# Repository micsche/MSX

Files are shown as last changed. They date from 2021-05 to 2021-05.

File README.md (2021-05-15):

# MSX
Recreate a Z80 system using MSX2 standard. 

The system is subdivided into 5 boards connected by a BUS. 

1. msx1-cpu: This is the CPU board complete with CPU, Clock circuit, Reset Circuit, IO Address decoder and default MSX Wait circuit.
2. msx1-memory : This is the 64k ROM/ 64k RAM circuit and a USB Serial connection via CJMCU-232H. Currently this is an MSX1 standard. 
3. msx1-keyb-ppi : This is the Keyboard connector circuit and the Memory Slot selector circuit
4. msx1-psg: This is the sound circuit (using YM2149). Joystick interface not implemented.
5. msx1-vdp: This is the video circuit (using TMS9958). To be completed: VRAM  of 96k possible.

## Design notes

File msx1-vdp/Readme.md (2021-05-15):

# MSX Video

This is a work in progress.

The VDP9958 is used (although this is not used until the MSX2+ standard)

The chip requires the use of DRAM chips. The use of SRAM would require complex address decode, out of the scope of this board development.
A 128k VRAM is possible with V9958.

The Video chips use the Z80 interrupt signal and also provide a CPU clock signal.

The video signal needs to be modified for use of new displays. LED displays cannot handle the 15kHz HSYNC frequency used by the chip.

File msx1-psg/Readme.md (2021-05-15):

# MSX Sound card 
(untested)

The soundcard uses stock YM2149 (AY-3-8910 clone)
The MSX also uses this chip to interface to the joysticks. This version of the board does not include joystick ports (scope for Future Work).

The sound is fed into the BUS pin J3-8. However, the board has enough space to include a small-speaker. (scope for Future Work)

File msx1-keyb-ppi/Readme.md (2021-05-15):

# MSX PPI - Keyboard Interface (as of writing untested)

This board has two functions:
1. Interface with a matrix keyboard (in progress), including an LED output for the CAPS lock key.
2. Provide SLOT Signalling standard of MSX

## Keyboard

The board has a DB25 connector where a keyboard is to be connected.
    


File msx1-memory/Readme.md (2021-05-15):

# MSX Memory Board

The aim of the board is to use stock ROM and SRAM,  had available. Although the ROM and RAM used are 128k, only 64k are used. An MSX memory mapper is a future project.
For MSX to use the memory the PPI board is a required board since it decodes the Memory Slot SLTSL signal. In this case SLOT0 is used for ROM and SLOT3 is used for RAM. However, for the SBC there is included a simple decoder that can be switched off.

The MSX1 standard: ROM is using the first 32k address 0000-7FFF (normally at SLOT0), and 8k-32k RAM the subsequent 8000-FFFF (Normally at SLOT3).
- https://www.msx.org/wiki/The_Memory
- https://konamiman.github.io/MSX2-Technical-Handbook/md/Chapter1.html#1-from-msx1-to-msx2



## Using the board for SBC operation
This board is adapted to be used as an SBC. A modification on the ROM should remove the A15 address decoding to use just 32k.
This is done using a 74LS139 that decodes the A15 and MREQ to produce the SLTSL0 and SLTSL3 selector signals. 
When used in MSX mode the 74LS139 can be disabled by disconnecting jumper SimpleMem (which powers the Logic Circuit).

## Serial Connection
The board also uses the IO Serial signal to connect a USB Serial connection to the Z80 databus. The circuit interfaces with a breakout board CJMCU-232H, which is TTL compliant.

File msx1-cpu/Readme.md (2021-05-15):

The aim of the board is to use stock hardware without the use of FPGAs, CPLDs, logic arrays, etc...
The chip count as a result increases considerably.

# MSX CPU board

This is a default CPU board complete with 
1. 3.58MHz clock circuit using a NAND invertor circuit. The board can choose which clock to using Jumpers CLK_EXT. Using an external clock circuit allows you to clock down the circuit for troubleshooting (logic analyser) or else use the VDPs own clock circuitry. 
The clock circuitry is included so that with the CPU board and Memory board, is effectively a standalone Z80 computer (SBC but not quite).

2. A reset circuit is included, with a Jumper (RESET_SWITCH) to connect an external reset button. Two signals are created RESET and ~RESET.
3. IO Signal circuitry. M1 and IORQ signal IO is being accessed. IO allocation reference: http://map.grauw.nl/resources/msx_io_ports.php
4. A wait circuit is used for slower Memory. Speedup modiciations include disabling this circuitry altogether. https://www.msx.org/forum/msx-talk/hardware/speeding-z80
5. 50-channel bus: Bus used to connect all the other boards together. This is not the cartridge bus as used by the MSX standard. The Bus includes
    i. Z80 Address Bus
    ii. Z80 Data Bus
    iii. Control Signals (CLK,INT, RD, WR, RESET,MREQ, IORQ)
    iv. IO Signals (rtc,ppi,psg,vdp,prn,exp,ser)
    


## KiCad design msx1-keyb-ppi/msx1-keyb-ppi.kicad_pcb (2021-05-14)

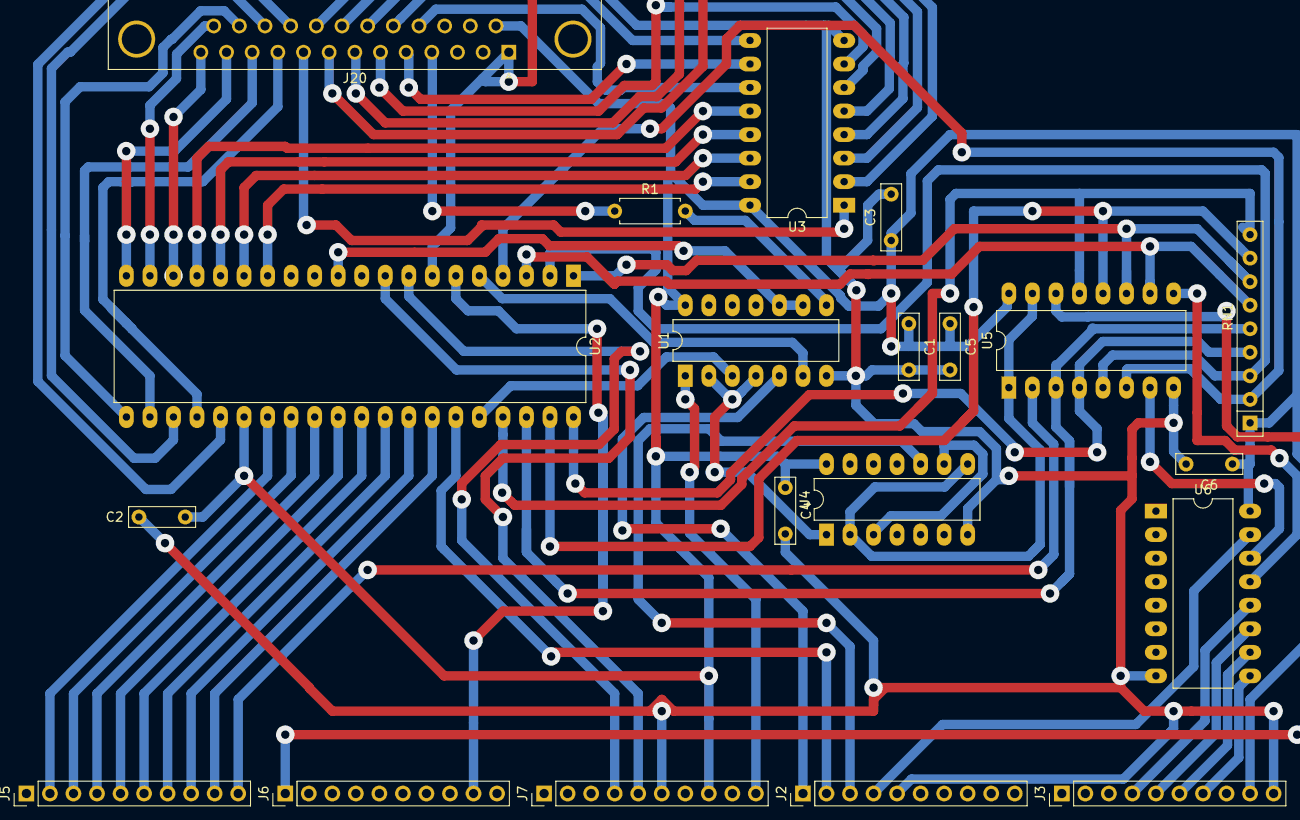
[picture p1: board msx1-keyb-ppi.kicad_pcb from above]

Board: 2 copper layers, 20 parts (0 on the bottom side), 64 nets.

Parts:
C1, C2, C3, C4, C5, C6: 100n; C_Rect_L7.0mm_W2.0mm_P5.00mm
J2, J3, J5, J6, J7: Conn_01x10; PinHeader_1x10_P2.54mm_Vertical
J20: DB25_Male_MountingHoles; DSUB-25_Male_Horizontal_P2.77x2.84mm_EdgePinOffset7.70mm_Ho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
R1: R; R_Axial_DIN0207_L6.3mm_D2.5mm_P7.62mm_Horizontal
RN1: 3.3k; R_Array_SIP9
U1: 74LS32; DIP-14_W7.62mm_LongPads
U2: PPI; DIP-40_W15.24mm_LongPads
U3: 74LS45; DIP-16_W10.16mm_LongPads
U4: 74LS00; DIP-14_W7.62mm_LongPads
U5: 74LS153; DIP-16_W10.16mm_LongPads
U6: 74LS139; DIP-16_W10.16mm_LongPads

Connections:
+5V: C1.1, C2.1, C3.1, C4.1, C5.1, C6.1, J3.9, J7.8, J20.14, RN1.1, U1.14, U2.26, U3.16, U4.14, U5.16, U6.16
A0: J7.5, U2.9
A1: J7.4, U2.8
A6: J6.9, U2.6
A14: J6.1, U5.14
A15: J5.10, U5.2
CAPS: J20.4, R1.1
D0: J5.9, U2.34
D1: J5.8, U2.33
D2: J5.7, U2.32
D3: J5.6, U2.31
D4: J5.5, U2.30
D5: J5.4, U2.29
D6: J5.3, U2.28
D7: J5.2, U2.27
GND: C1.2, C2.2, C3.2, C4.2, C5.2, C6.2, J2.5, J3.10, J7.6, J20.1, U1.7, U2.7, U3.8, U4.7, U5.8, U6.8
unnamed: R1.2, U1.8
unnamed: RN1.2, U2.4, U5.6
unnamed: RN1.3, U2.2, U5.5
unnamed: RN1.4, U2.40, U5.4
unnamed: RN1.5, U2.38, U5.3
unnamed: RN1.6, U2.3, U5.10
unnamed: RN1.7, U2.1, U5.11
unnamed: RN1.8, U2.39, U5.12
unnamed: RN1.9, U2.37, U5.13
unnamed: U1.3, U2.36
unnamed: U1.6, U2.5
unnamed: U1.9, U1.10, U2.11
unnamed: U2.14, U3.15
unnamed: U2.15, U3.14
unnamed: U2.16, U3.13
unnamed: U2.17, U3.12
unnamed: U4.2, U4.8, U5.1, U5.15
unnamed: U4.3, U4.9
unnamed: U5.7, U6.14
unnamed: U5.9, U6.13
RESET: J2.2, U2.35
S0: J20.13, U2.18
S1: J20.25, U2.19
S2: J20.12, U2.20
S3: J20.24, U2.21
S4: J20.11, U2.22
S5: J20.23, U2.23
S6: J20.10, U2.24
S7: J20.22, U2.25
Y0: J20.9, U3.1
Y1: J20.21, U3.2
Y2: J20.8, U3.3
Y3: J20.20, U3.4
Y4: J20.7, U3.5
Y5: J20.19, U3.6
Y6: J20.6, U3.7
Y7: J20.18, U3.9
Y8: J20.5, U3.10
Y9: J20.17, U3.11
~MREQ: J2.4, U6.15
~PPI: U1.2, U1.4, U4.1
~RD: J2.1, U1.5
~RESET: J2.3, U4.10
~SLTSL0: J3.4, U6.12
~SLTSL1: J3.5, U6.11
~SLTSL2: J3.6, U6.10
~SLTSL3: J3.7, U6.9
~WR: J7.10, U1.1

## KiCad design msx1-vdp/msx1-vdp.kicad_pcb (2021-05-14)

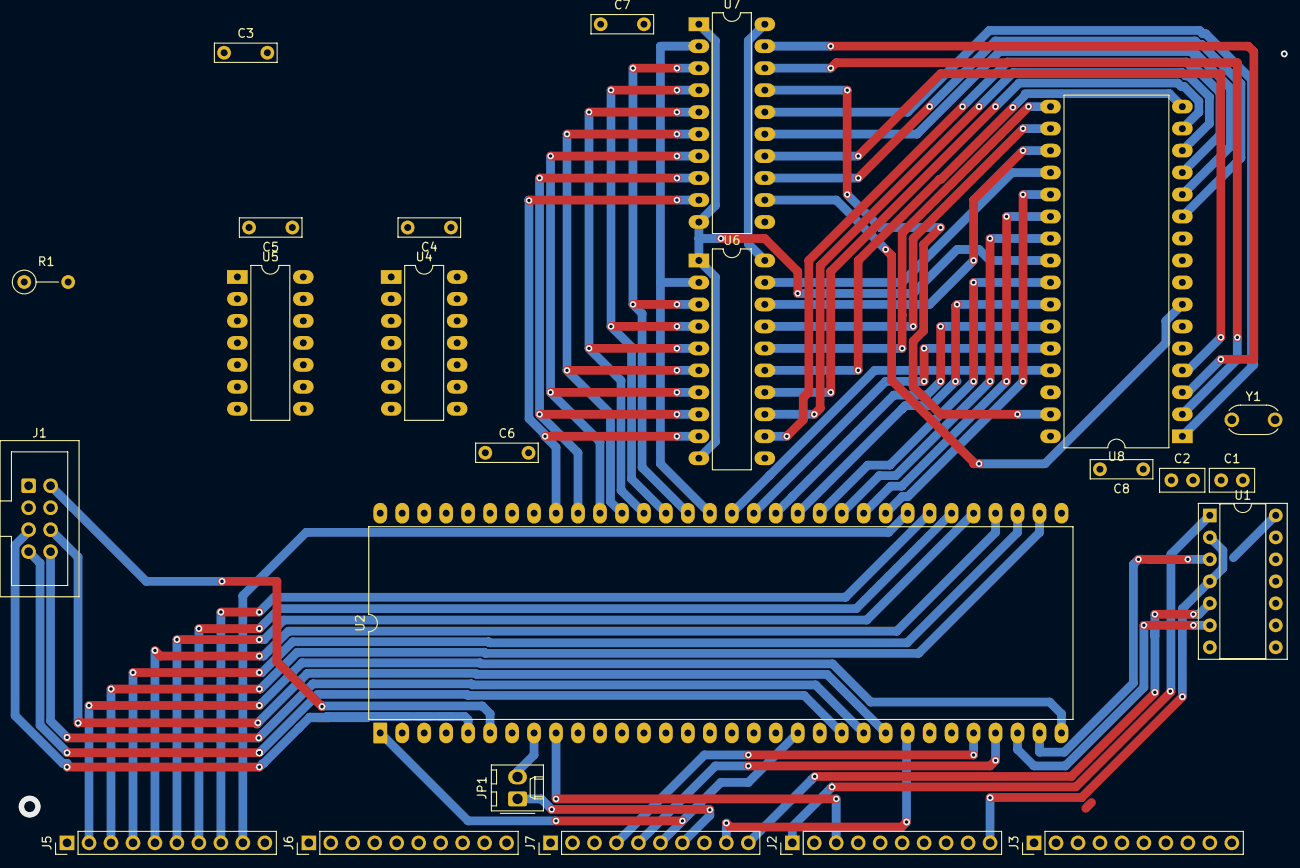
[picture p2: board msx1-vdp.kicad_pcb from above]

Board: 2 copper layers, 24 parts (0 on the bottom side), 70 nets.

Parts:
C1: 15pf; C_Disc_D5.0mm_W2.5mm_P2.50mm
C2: 7pF; C_Disc_D5.0mm_W2.5mm_P2.50mm
C3, C4, C5, C6, C7, C8: C; C_Rect_L7.0mm_W2.0mm_P5.00mm
J1: Conn_02x03_Counter_Clockwise; IDC-Header_2x04_P2.54mm_Vertical
J2, J3, J5, J6, J7: Conn_01x10; PinHeader_1x10_P2.54mm_Vertical
JP1: Jumper_NO_Small; Molex_KK-254_AE-6410-02A_1x02_P2.54mm_Vertical
R1: 330; R_Axial_DIN0207_L6.3mm_D2.5mm_P5.08mm_Vertical
U1: 74LS32; DIP-14_W7.62mm_Socket
U2: TMS9958-MSX; DIP-64_W25.4mm_LongPads
U4: 74LS00; DIP-14_W7.62mm_LongPads
U5: 74LS74; DIP-14_W7.62mm_LongPads
U6, U7: 74LS574; DIP-20_W7.62mm_LongPads
U8: 551001; DIP-32_W15.24mm_LongPads
Y1: 21.47727MHz; Resonator-2Pin_W6.0mm_H3.0mm

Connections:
+5V: C3.1, C4.1, C5.1, C6.1, C7.1, C8.1, J1.1, J3.9, J7.8, U1.14, U2.21, U2.58, U4.14, U5.4, U5.14, U6.20, U7.20, U8.8
A0: J7.5, U2.29
A1: J7.4, U2.28
ADD_DATA_0: U2.49, U6.2, U7.2
ADD_DATA_1: U2.50, U6.3, U7.3
ADD_DATA_2: U2.51, U6.4, U7.4
ADD_DATA_3: U2.52, U6.5, U7.5
ADD_DATA_4: U2.53, U6.6, U7.6
ADD_DATA_5: U2.54, U6.7, U7.7
ADD_DATA_6: U2.55, U6.8, U7.8
ADD_DATA_7: U2.56, U6.9, U7.9
B: J1.6, U2.24
CAS: U4.3, U4.12, U4.13, U5.3, U7.11
CLK: J7.7, JP1.1
CSYNC: J1.2, U2.6
D0: J5.9, U2.40
D1: J5.8, U2.39
D2: J5.7, U2.38
D3: J5.6, U2.37
D4: J5.5, U2.36
D5: J5.4, U2.35
D6: J5.3, U2.34
D7: J5.2, U2.32
DATA0: U2.41, U8.21
DATA1: U2.42, U8.22
DATA2: U2.43, U8.23
DATA3: U2.44, U8.25
DATA4: U2.45, U8.26
DATA5: U2.46, U8.27
DATA6: U2.47, U8.28
DATA7: U2.48, U8.29
G: J1.7, U2.22
GND: C1.1, C2.1, C3.2, C4.2, C5.2, C6.2, C7.2, C8.2, J1.4, J2.5, J3.10, J7.6, U1.7, U2.1, U2.20, U4.7, U5.1, U5.7, U6.1, U6.10, U7.1, U7.10, U8.24
unnamed: C1.2, R1.1, Y1.1
unnamed: C2.2, U2.63, Y1.2
unnamed: JP1.2, U2.8
unnamed: R1.2, U2.64
unnamed: U1.3, U2.31
unnamed: U1.6, U2.30
unnamed: U2.60, U4.2, U5.2
unnamed: U2.61, U4.1
unnamed: U4.6, U6.11
unnamed: U4.8, U8.32
unnamed: U4.11, U8.6, U8.30
unnamed: U5.5, U8.10
unnamed: U6.12, U8.13
unnamed: U6.13, U8.14
unnamed: U6.14, U8.15
unnamed: U6.15, U8.16
unnamed: U6.16, U8.17
unnamed: U6.17, U8.18
unnamed: U6.18, U8.19
unnamed: U6.19, U8.20
unnamed: U7.12, U8.7
unnamed: U7.13, U8.11
unnamed: U7.14, U8.4
unnamed: U7.15, U8.12
unnamed: U7.16, U8.1
unnamed: U7.17, U8.31
unnamed: U7.18, U8.2
unnamed: U7.19, U8.3
R: J1.8, U2.23
R_~W: U2.57, U4.9, U4.10, U8.5
vdp_en: J2.10, U1.2, U1.4
~HSYNC: J1.5, U2.5
~INT: J7.9, U2.25
~RAS: U2.62, U4.4, U4.5
~RD: J2.1, U1.1
~RESET: J2.3, U2.9
~WR: J7.10, U1.5

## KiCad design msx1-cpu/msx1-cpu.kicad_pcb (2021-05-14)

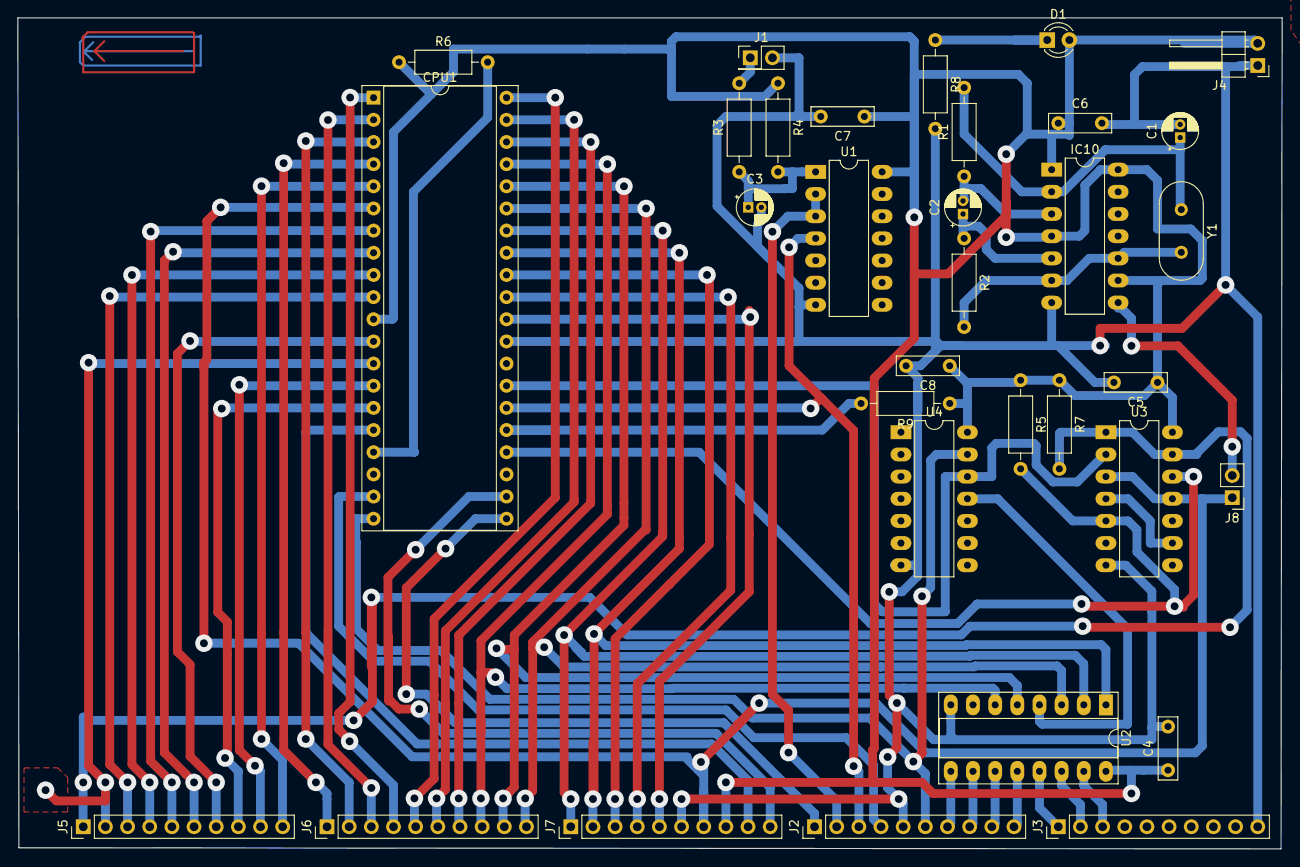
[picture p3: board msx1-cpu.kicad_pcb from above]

Board: 2 copper layers, 144.9 x 95.2 mm, 33 parts (0 on the bottom side), 56 nets.

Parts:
C1: 120p; CP_Radial_D4.0mm_P1.50mm
C2: 100n; CP_Radial_D4.0mm_P1.50mm
C3: 1nF; CP_Radial_D4.0mm_P1.50mm
C4, C5, C7, C8: 100n; C_Rect_L7.0mm_W2.0mm_P5.00mm
C6: 220n; C_Rect_L7.0mm_W2.0mm_P5.00mm
CPU1: Z80CPU; DIP-40_W15.24mm_Socket
D1: LED; LED_D3.0mm_FlatTop
IC10: 74LS00; DIP-14_W7.62mm_LongPads
J1: RESET SWITCH; PinHeader_2x01_P2.54mm_Vertical
J2, J3, J5, J6, J7: Conn_01x10; PinHeader_1x10_P2.54mm_Vertical
J4: Conn_02x01; PinHeader_1x02_P2.54mm_Horizontal
J8: CLK_EXT; PinHeader_1x02_P2.54mm_Vertical
R1, R2: 330; R_Axial_DIN0207_L6.3mm_D2.5mm_P10.16mm_Horizontal
R3: 100R; R_Axial_DIN0207_L6.3mm_D2.5mm_P10.16mm_Horizontal
R4: 47k; R_Axial_DIN0207_L6.3mm_D2.5mm_P10.16mm_Horizontal
R5, R6, R7, R9: 10k; R_Axial_DIN0207_L6.3mm_D2.5mm_P10.16mm_Horizontal
R8: 220; R_Axial_DIN0207_L6.3mm_D2.5mm_P10.16mm_Horizontal
U1: 74HC14; DIP-14_W7.62mm_LongPads
U2: 74LS138; DIP-16_W7.62mm_Socket_LongPads
U3: 74LS74; DIP-14_W7.62mm_LongPads
U4: 74LS32; DIP-14_W7.62mm_LongPads
Y1: 3.58MHz; Crystal_HC18-U_Vertical

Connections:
+5V: C4.1, C5.1, C6.1, C7.1, C8.1, CPU1.11, D1.2, IC10.1, IC10.4, IC10.9, IC10.14, J4.2, J7.8, R4.1, R5.1, R6.1, R7.1, R9.1, U1.14, U2.16, U3.14, U4.14
A0: CPU1.30, J7.5
A1: CPU1.31, J7.4
A2: CPU1.32, J7.3
A3: CPU1.33, J7.2, U2.1
A4: CPU1.34, J7.1, U2.2
A5: CPU1.35, J6.10, U2.3
A6: CPU1.36, J6.9, U2.5
A7: CPU1.37, J6.8, U2.6
A8: CPU1.38, J6.7
A9: CPU1.39, J6.6
A10: CPU1.40, J6.5
A11: CPU1.1, J6.4
A12: CPU1.2, J6.3
A13: CPU1.3, J6.2
A14: CPU1.4, J6.1
A15: CPU1.5, J5.10
CLK: CPU1.6, J7.7, J8.1, U3.3, U3.11
CLK2: IC10.8, J8.2
D0: CPU1.14, J5.9
D1: CPU1.15, J5.8
D2: CPU1.12, J5.7
D3: CPU1.8, J5.6
D4: CPU1.7, J5.5
D5: CPU1.9, J5.4
D6: CPU1.10, J5.3
D7: CPU1.13, J5.2
GND: C1.2, C3.2, C4.2, C5.2, C6.2, C7.2, C8.2, CPU1.29, IC10.7, J1.2, J2.5, J3.10, J4.1, J7.6, R8.2, U1.7, U2.8, U3.7, U4.7
unnamed: C1.1, IC10.2, R1.2, Y1.1
unnamed: C2.1, IC10.5, R2.1
unnamed: C2.2, IC10.3, R1.1
unnamed: C3.1, R3.1, R4.2, U1.1
unnamed: CPU1.17, R6.2
unnamed: CPU1.25, R9.2
unnamed: D1.1, R8.1
unnamed: IC10.6, IC10.10, R2.2, Y1.2
unnamed: J1.1, R3.2
unnamed: U2.4, U4.11
unnamed: U3.4, U3.9
RESET: J2.2, U1.2, U1.3
exp1_en: J3.2, U2.14
ppi_en: J2.8, U2.10
prn_en: J3.1, U2.13
psg_en: J2.9, U2.11
rtc_en: J2.7, U2.9
ser_en: J3.3, U2.15
vdp_en: J2.10, U2.12
~INT: CPU1.16, J7.9
~IORQ: CPU1.20, J2.6, U4.13
~IO_WAIT: J5.1, R7.2, U3.1, U3.13
~M1: CPU1.27, U3.2, U4.12
~MREQ: CPU1.19, J2.4
~RD: CPU1.21, J2.1
~RESET: CPU1.26, J2.3, U1.4
~WAIT: CPU1.24, R5.2, U3.5, U3.12
~WR: CPU1.22, J7.10

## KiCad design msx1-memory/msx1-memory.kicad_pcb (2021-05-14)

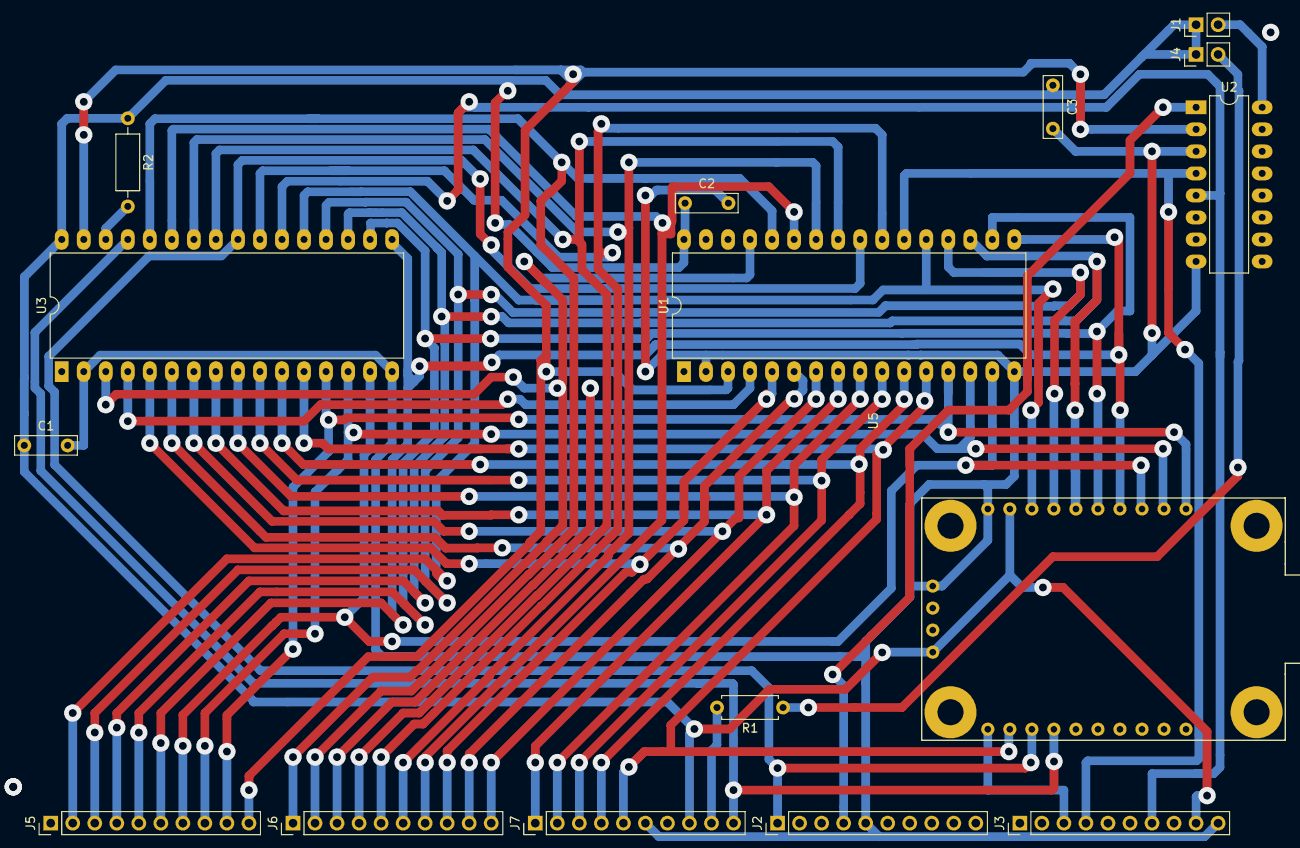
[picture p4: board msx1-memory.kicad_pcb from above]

Board: 2 copper layers, 16 parts (0 on the bottom side), 36 nets.

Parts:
C1, C2, C3: 100n; C_Rect_L7.0mm_W2.0mm_P5.00mm
J1: SimpleMem; PinHeader_1x02_P2.54mm_Vertical
J2, J3, J5, J6, J7: Conn_01x10; PinHeader_1x10_P2.54mm_Vertical
J4: SimpleMem-INT; PinHeader_1x02_P2.54mm_Vertical
R1: 10k; R_Axial_DIN0207_L6.3mm_D2.5mm_P7.62mm_Horizontal
R2: 10k; R_Axial_DIN0207_L6.3mm_D2.5mm_P10.16mm_Horizontal
U1: ROM 29F010; DIP-32_W15.24mm_LongPads
U2: 74LS139; DIP-16_W7.62mm_LongPads
U3: SRAM TC551001; DIP-32_W15.24mm_LongPads
U5: CJMCU-232H; CJMCU-232H-Breakout

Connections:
+5V: C1.1, C2.1, C3.1, J1.1, J3.9, J4.1, J7.8, R2.1, U1.32, U3.32, U5.9, U5.14
A0: J7.5, U1.12, U3.12, U5.16
A1: J7.4, U1.11, U3.11
A2: J7.3, U1.10, U3.10
A3: J7.2, U1.9, U3.9
A4: J7.1, U1.8, U3.8
A5: J6.10, U1.7, U3.7
A6: J6.9, U1.6, U3.6
A7: J6.8, U1.5, U3.5
A8: J6.7, U1.27, U3.27
A9: J6.6, U1.26, U3.26
A10: J6.5, U1.23, U3.23
A11: J6.4, U1.25, U3.25
A12: J6.3, U1.4, U3.4
A13: J6.2, U1.28, U3.28
A14: J6.1, U1.29, U3.3
A15: J5.10, U1.3, U2.2, U3.31
D0: J5.9, U1.13, U3.13, U5.1
D1: J5.8, U1.14, U3.14, U5.2
D2: J5.7, U1.15, U3.15, U5.3
D3: J5.6, U1.17, U3.17, U5.4
D4: J5.5, U1.18, U3.18, U5.5
D5: J5.4, U1.19, U3.19, U5.6
D6: J5.3, U1.20, U3.20, U5.7
D7: J5.2, U1.21, U3.21, U5.8
GND: C1.2, C2.2, C3.2, J2.5, J3.10, J7.6, U1.2, U1.16, U2.3, U2.8, U3.2, U3.16, U5.10, U5.11
unnamed: J1.2, U2.16
unnamed: J4.2, R1.1
unnamed: R2.2, U3.30
ser_en: J3.3, U5.15
~INT: J7.9, R1.2
~MREQ: J2.4, U2.1
~RD: J2.1, U1.24, U3.24, U5.17
~SLTSL0: J3.4, U1.22, U2.4
~SLTSL3: J3.7, U2.5, U3.22
~WR: J7.10, U3.29, U5.18

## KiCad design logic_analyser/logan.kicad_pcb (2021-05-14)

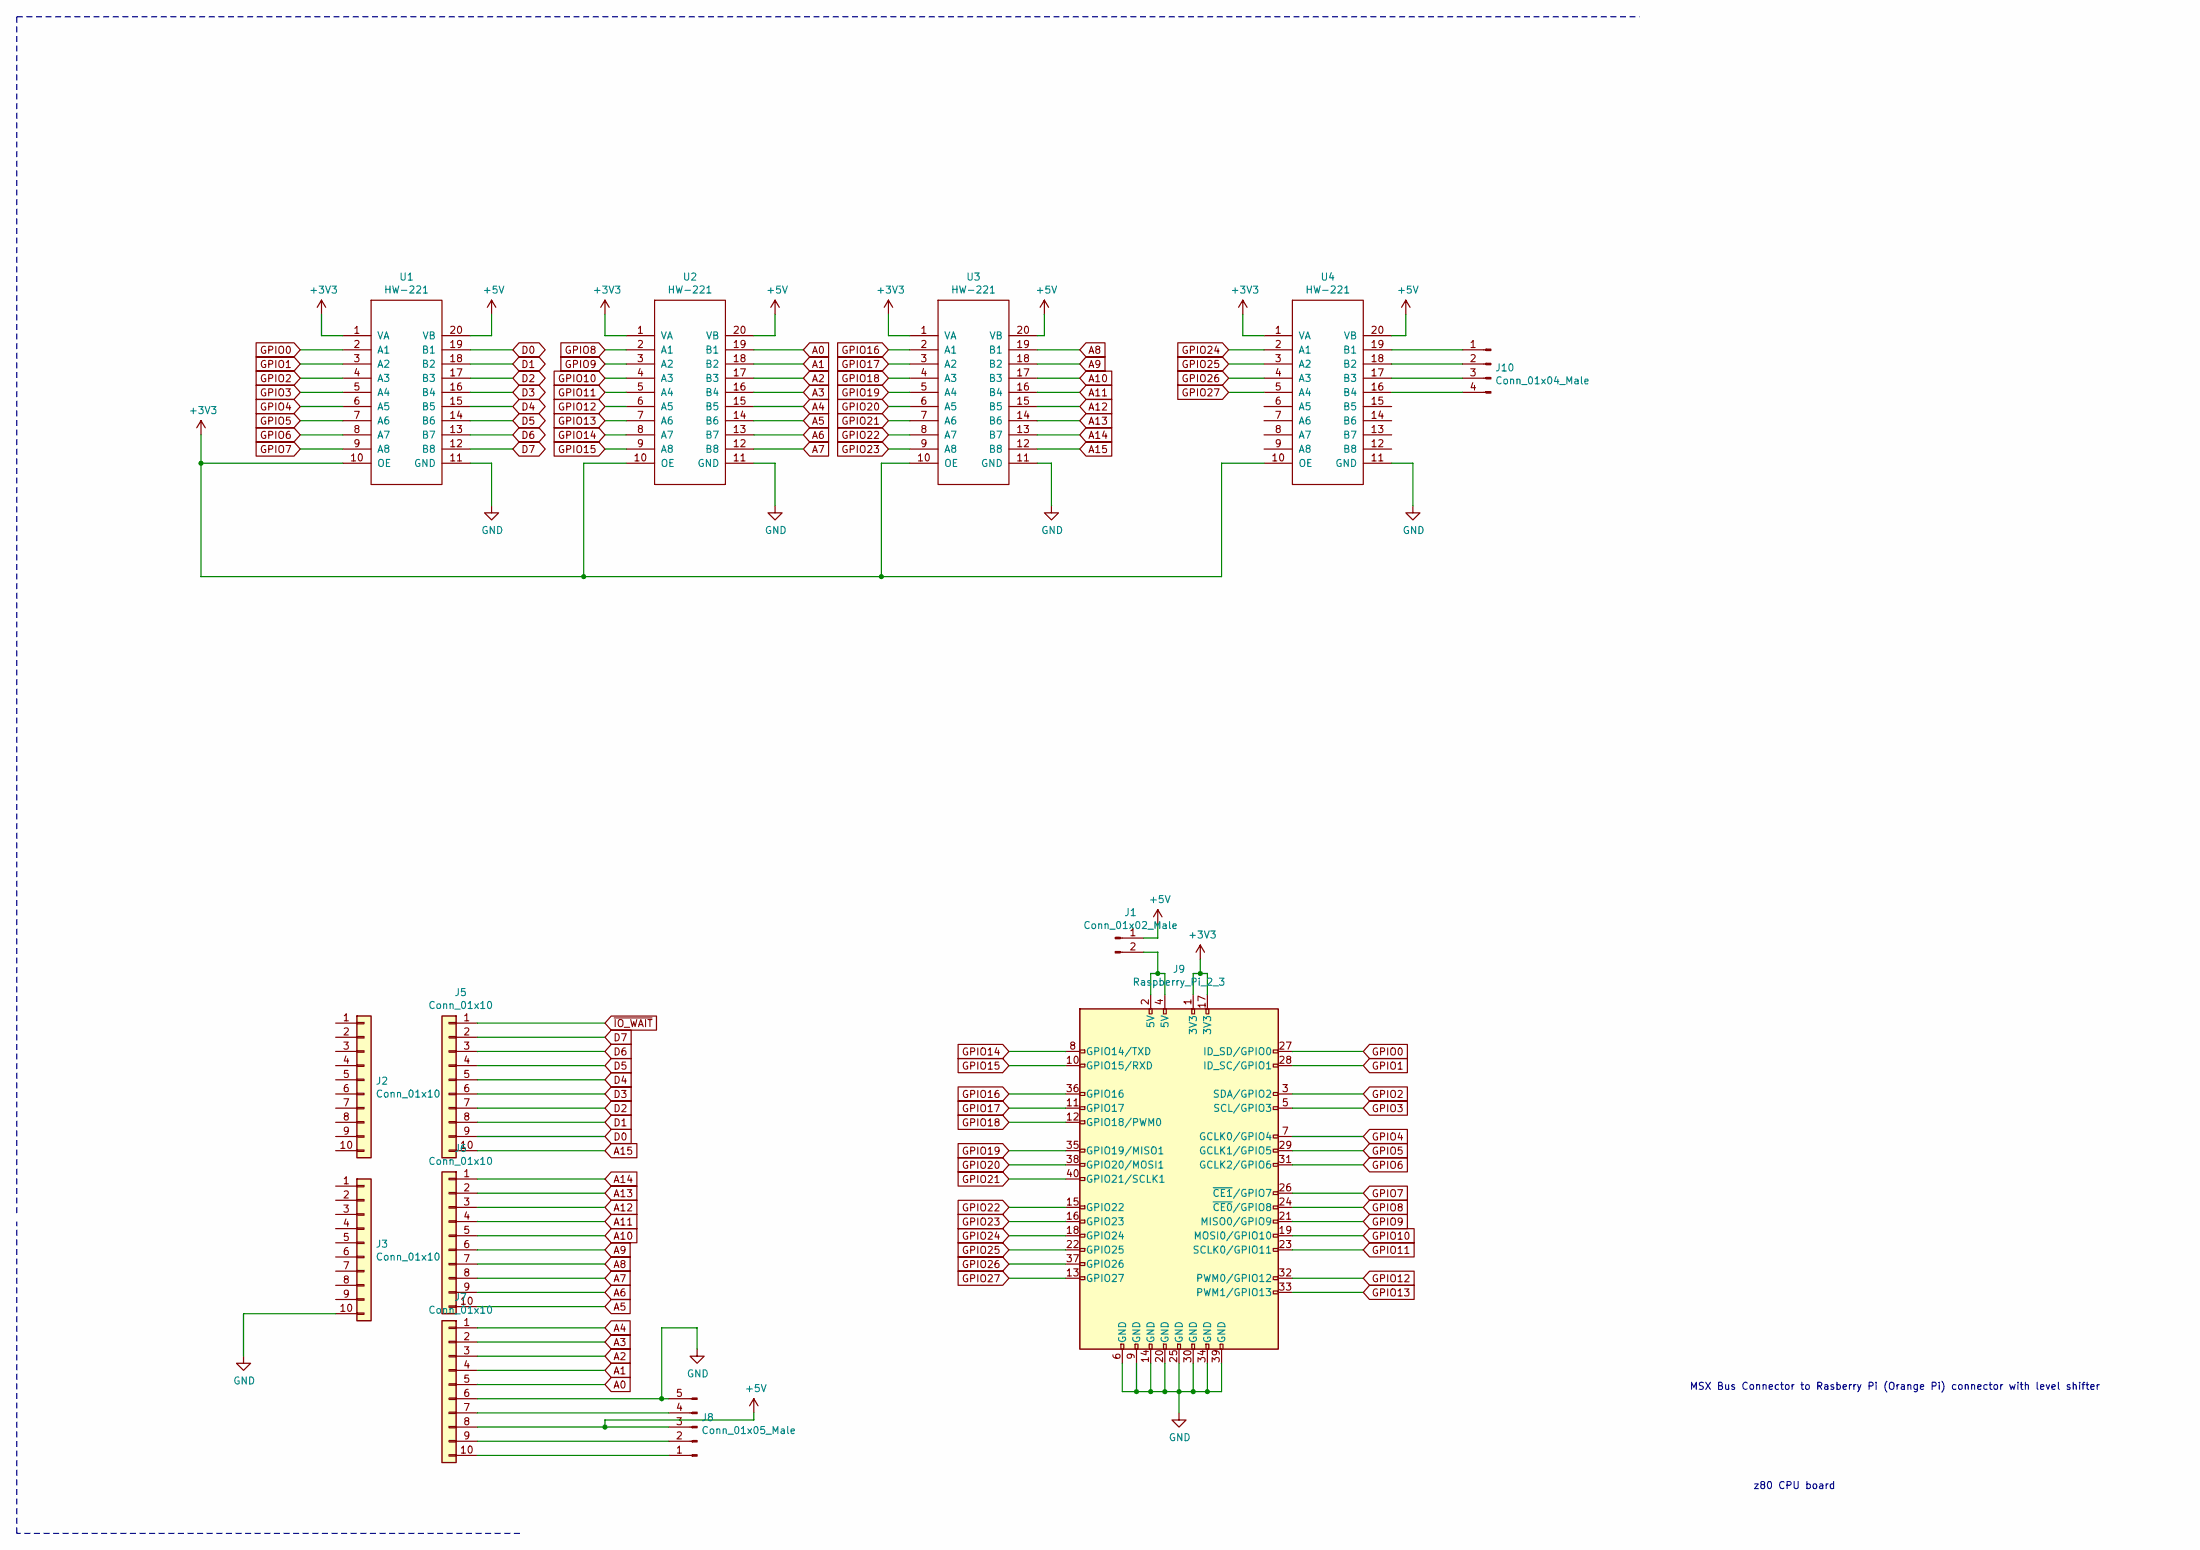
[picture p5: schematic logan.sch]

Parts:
J1: Conn_01x02_Male; PinHeader_1x02_P2.54mm_Vertical
J2, J3, J5, J6, J7: Conn_01x10; PinHeader_1x10_P2.54mm_Vertical
J8: Conn_01x05_Male; PinHeader_1x05_P2.54mm_Vertical
J9: Raspberry_Pi_2_3; PinHeader_2x20_P2.54mm_Vertical
J10: Conn_01x04_Male; PinHeader_1x04_P2.54mm_Vertical
U1, U2, U3, U4: HW-221; hw-221_breakout

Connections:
+3V3: J9.1 (3V3), J9.17 (3V3), U1.1 (VA), U1.10 (OE), U2.1 (VA), U2.10 (OE), U3.1 (VA), U3.10 (OE), U4.1 (VA), U4.10 (OE)
+5V: J1.1, J7.8, J8.3, U1.20 (VB), U2.20 (VB), U3.20 (VB), U4.20 (VB)
A0: J7.5, U2.19 (B1)
A1: J7.4, U2.18 (B2)
A2: J7.3, U2.17 (B3)
A3: J7.2, U2.16 (B4)
A4: J7.1, U2.15 (B5)
A5: J6.10, U2.14 (B6)
A6: J6.9, U2.13 (B7)
A7: J6.8, U2.12 (B8)
A8: J6.7, U3.19 (B1)
A9: J6.6, U3.18 (B2)
A10: J6.5, U3.17 (B3)
A11: J6.4, U3.16 (B4)
A12: J6.3, U3.15 (B5)
A13: J6.2, U3.14 (B6)
A14: J6.1, U3.13 (B7)
A15: J5.10, U3.12 (B8)
D0: J5.9, U1.19 (B1)
D1: J5.8, U1.18 (B2)
D2: J5.7, U1.17 (B3)
D3: J5.6, U1.16 (B4)
D4: J5.5, U1.15 (B5)
D5: J5.4, U1.14 (B6)
D6: J5.3, U1.13 (B7)
D7: J5.2, U1.12 (B8)
GND: J3.10, J7.6, J8.5, J9.6 (GND), J9.9 (GND), J9.14 (GND), J9.20 (GND), J9.25 (GND), J9.30 (GND), J9.34 (GND), J9.39 (GND), U1.11 (GND), U2.11 (GND), U3.11 (GND), U4.11 (GND)
GPIO0: J9.27 (ID_SD/GPIO0), U1.2 (A1)
GPIO1: J9.28 (ID_SC/GPIO1), U1.3 (A2)
GPIO2: J9.3 (SDA/GPIO2), U1.4 (A3)
GPIO3: J9.5 (SCL/GPIO3), U1.5 (A4)
GPIO4: J9.7 (GCLK0/GPIO4), U1.6 (A5)
GPIO5: J9.29 (GCLK1/GPIO5), U1.7 (A6)
GPIO6: J9.31 (GCLK2/GPIO6), U1.8 (A7)
GPIO7: J9.26 (~CE1~/GPIO7), U1.9 (A8)
GPIO8: J9.24 (~CE0~/GPIO8), U2.2 (A1)
GPIO9: J9.21 (MISO0/GPIO9), U2.3 (A2)
GPIO10: J9.19 (MOSI0/GPIO10), U2.4 (A3)
GPIO11: J9.23 (SCLK0/GPIO11), U2.5 (A4)
GPIO12: J9.32 (PWM0/GPIO12), U2.6 (A5)
GPIO13: J9.33 (PWM1/GPIO13), U2.7 (A6)
GPIO14: J9.8 (GPIO14/TXD), U2.8 (A7)
GPIO15: J9.10 (GPIO15/RXD), U2.9 (A8)
GPIO16: J9.36 (GPIO16), U3.2 (A1)
GPIO17: J9.11 (GPIO17), U3.3 (A2)
GPIO18: J9.12 (GPIO18/PWM0), U3.4 (A3)
GPIO19: J9.35 (GPIO19/MISO1), U3.5 (A4)
GPIO20: J9.38 (GPIO20/MOSI1), U3.6 (A5)
GPIO21: J9.40 (GPIO21/SCLK1), U3.7 (A6)
GPIO22: J9.15 (GPIO22), U3.8 (A7)
GPIO23: J9.16 (GPIO23), U3.9 (A8)
GPIO24: J9.18 (GPIO24), U4.2 (A1)
GPIO25: J9.22 (GPIO25), U4.3 (A2)
GPIO26: J9.37 (GPIO26), U4.4 (A3)
GPIO27: J9.13 (GPIO27), U4.5 (A4)
unnamed: J1.2, J9.2 (5V), J9.4 (5V)
unnamed: J7.7, J8.4
unnamed: J7.9, J8.2
unnamed: J7.10, J8.1
unnamed: J10.1, U4.19 (B1)
unnamed: J10.2, U4.18 (B2)
unnamed: J10.3, U4.17 (B3)
unnamed: J10.4, U4.16 (B4)
~IO_WAIT: J5.1

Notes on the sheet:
MSX Bus Connector to Rasberry Pi (Orange Pi) connector with level shifter
z80 CPU board

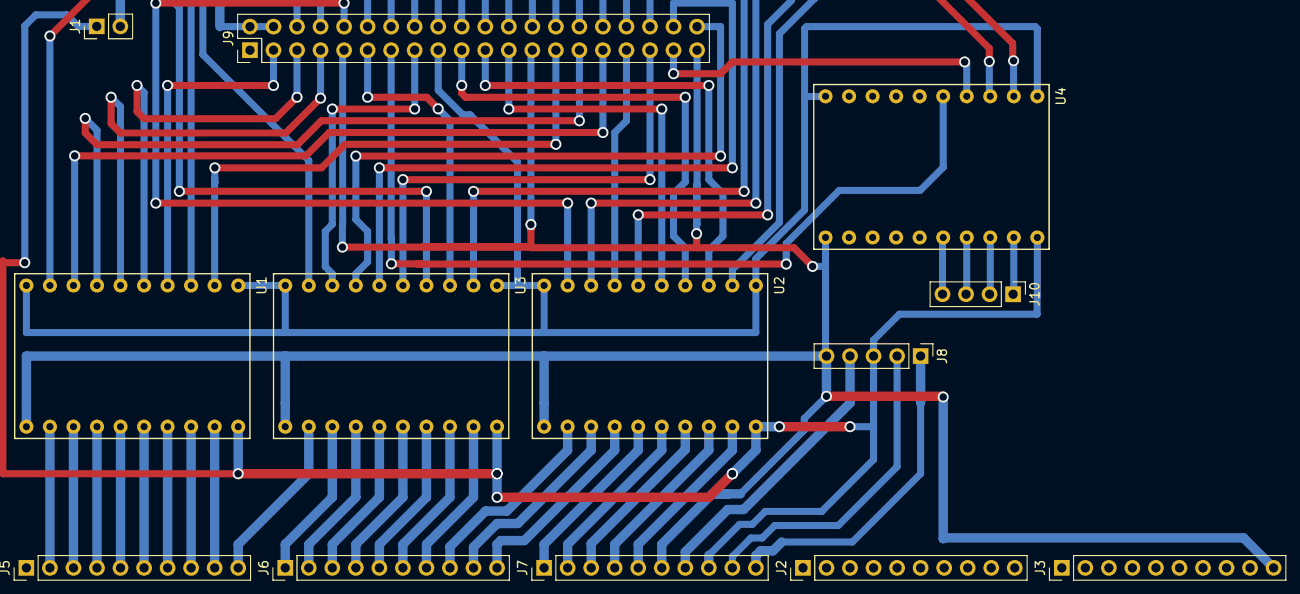
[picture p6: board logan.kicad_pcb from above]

Board: 2 copper layers, 13 parts (0 on the bottom side), 63 nets.

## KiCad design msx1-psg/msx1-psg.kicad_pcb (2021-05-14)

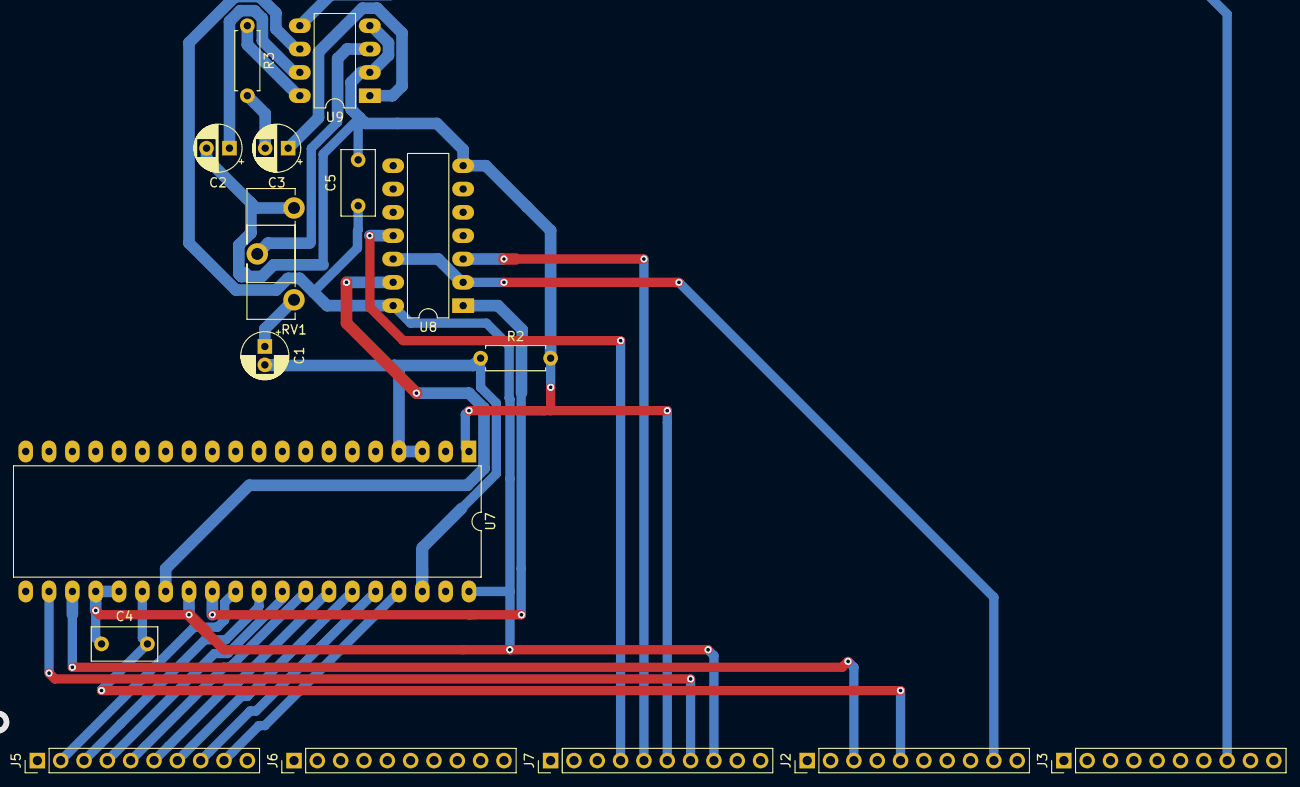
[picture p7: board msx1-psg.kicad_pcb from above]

Board: 2 copper layers, 16 parts (0 on the bottom side), 25 nets.

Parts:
C1: 10u; CP_Radial_D5.0mm_P2.00mm
C2: 47u; CP_Radial_D5.0mm_P2.50mm
C3: 10u; CP_Radial_D5.0mm_P2.50mm
C4, C5: C; C_Rect_L7.0mm_W3.5mm_P5.00mm
J2, J3, J5, J6, J7: Conn_01x10; PinHeader_1x10_P2.54mm_Vertical
R2: 470R; R_Axial_DIN0207_L6.3mm_D2.5mm_P7.62mm_Horizontal
R3: 1.2k; R_Axial_DIN0207_L6.3mm_D2.5mm_P7.62mm_Horizontal
RV1: 10k; Potentiometer_ACP_CA14-H4_Horizontal
U7: YM2149; DIP-40_W15.24mm_LongPads
U8: 74LS02; DIP-14_W7.62mm_LongPads
U9: LM386; DIP-8_W7.62mm_LongPads

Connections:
+5V: C4.1, C5.1, J3.9, J7.8, U7.24, U7.25, U7.28, U7.40, U8.14, U9.6
A0: J7.5, U8.3
A1: J7.4, U8.11
CLK: J7.7, U7.22
D0: J5.9, U7.37
D1: J5.8, U7.36
D2: J5.7, U7.35
D3: J5.6, U7.34
D4: J5.5, U7.33
D5: J5.4, U7.32
D6: J5.3, U7.31
D7: J5.2, U7.30
GND: C2.2, C4.2, C5.2, J2.5, J3.10, J7.6, R2.2, RV1.3, U7.1, U7.26, U8.7, U9.2, U9.4
unnamed: C1.1, RV1.1
unnamed: C1.2, R2.1, U7.3, U7.4, U7.38
unnamed: C2.1, U9.7
unnamed: C3.1, U9.1
unnamed: C3.2, R3.2
unnamed: R3.1, U9.8
unnamed: RV1.2, U9.3
unnamed: U7.27, U8.13
unnamed: U7.29, U8.1
SND: J3.8, U9.5
psg_en: J2.9, U8.2, U8.12
~RESET: J2.3, U7.23

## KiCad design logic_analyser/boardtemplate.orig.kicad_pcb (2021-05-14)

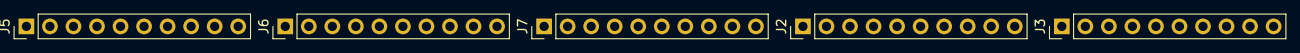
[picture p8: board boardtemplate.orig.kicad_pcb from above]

Board: 2 copper layers, 5 parts (0 on the bottom side), 2 nets.

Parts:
J2, J3, J5, J6, J7: Conn_01x10; PinHeader_1x10_P2.54mm_Vertical

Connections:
+5V: J3.9, J7.8
GND: J2.5, J3.10, J7.6
